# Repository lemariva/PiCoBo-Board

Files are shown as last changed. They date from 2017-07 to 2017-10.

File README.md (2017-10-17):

# PiCoBo-Board 

**PiCoBo** is a multi-target board. I designed it using the **MSP430G2553** (20/28 pin version), which is part of the MSP430 Texas Instruments family of ultra-low-power microcontrollers. 

The board includes also a **CP2102** which can be used for communication over UART. 

The board can be supplied using a C2032 battery, over USB or external DC source up to 10V. It uses a **TPS77301DGK** to regulate the max. voltage of 3.6V needed for the MSP430. 

Up to three **IRLL2705** can be soldered to the board to switch on/off directly (or using PWM) voltages up to 55V and 3.8A. Additionall multiple pinouts are available to connect external sensors (e.g. **DHT11**), servo motors, leds etc. For testing uses it can be programmed using the MSP430G2553 LaunchPad.

Applications
-------------------
* Ultra-low-power sensor: 
	* Temperature
	* Humidity
	* Air quality
	* Light condition
	* Door or window open/close status
	* etc
* Servo controller
* RGB LED controller
* X actuator
* etc

PCB Boards
-----
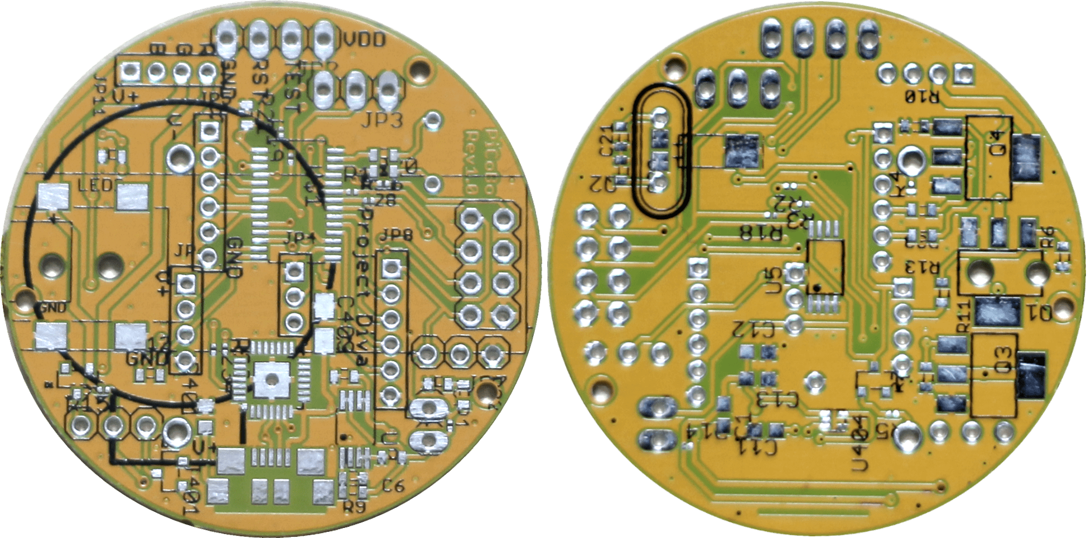
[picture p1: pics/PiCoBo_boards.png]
PCB Boards


More Info: 
-------------------

* Blog article related to this project: https://goo.gl/yuvsjp
* Code example: https://goo.gl/CPGcYK
* Datasheet MSP430G2553: http://www.ti.com/product/MSP430G2553

Changelog
-------------------
* Revision: 1.1v

License
--------------------
Apache 2.0

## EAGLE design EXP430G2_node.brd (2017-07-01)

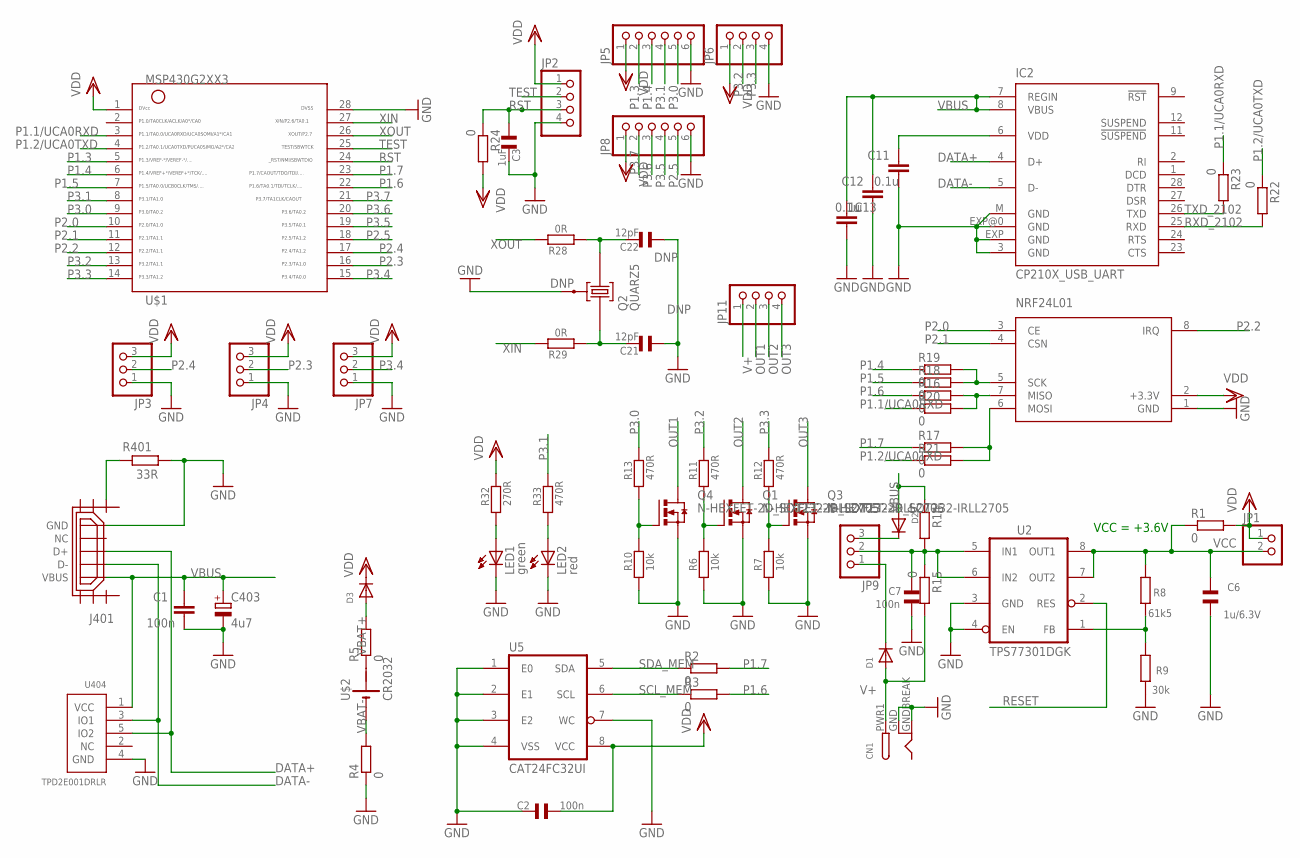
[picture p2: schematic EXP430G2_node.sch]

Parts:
C1: 100n; C0603
C2, C7: 100n; 0603
C3: 1uF; 0603
C6: 1u/6.3V; 0603
C11, C13: 0.1u; C0603
C12: 1u; C0603
C21, C22: 12pF; 0603
C403: 4u7; A/3216-18R
CN1: DCBARRELSMT; DCJACK_2MM_SMT
D1, D2, D3: DIODESOT23_REFLOW; SOT23-R
IC2: CP210X_USB_UART; MLP28
J401: USB_MICRO_FLIPPED; HIROSE-ZX62R-B-5P
JP1: PINHD-1X2; 1X02
JP2: PINHD-1X4; 1X04
JP3, JP7, JP9: PINHD-1X3; 1X03
JP4: PINHD-1X3_2.00; 1X03M
JP5, JP8: PINHD-1X6_2.00; 1X06M
JP6, JP11: PINHD-1X4_2.00; 1X04M
LED1: green; DIODE0603
LED2: red; DIODE0603
NRF24L01: NRF24L01HP; NRF24L01_HP
Q1, Q3, Q4: N-HEXFET-2D_SOT232-IRLL2705; SOT223
Q2: QUARZ5
R1, R2, R3, R4, R5, R14, R15, R16, R17, R18, R19, R20, R21, R22, R23, R24: 0; R0201
R6, R7, R10: 10k; 0603
R8: 61k5; 0603
R9: 30k; 0603
R11, R12, R13, R33: 470R; 0603
R28, R29: 0R; 0603
R32: 270R; 0603
R401: 33R; R0603
U2: TPS77301DGK; MSOP8
U5: CAT24FC32UI; TSSOP8
U404: TPD2E001DRLR; TPD2E001-DRL
U$1: G2XX3---PW28; PW28
U$2: CR2032

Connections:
DATA+: IC2.4 (D+), J401.D+, U404.5 (IO2)
DATA-: IC2.5 (D-), J401.D-, U404.3 (IO1)
GND: C1.2, C2.2, C3.2, C6.2, C7.1, C11.2, C12.2, C13.2, C21.1, C22.1, C403.-, CN1.GND (GNDBREAK), CN1.GNDBREAK (GND), IC2.3 (GND), IC2.EXP (GND), IC2.EXP@0 (GND), IC2.M (GND), J401.GND, JP2.4, JP3.1, JP4.1, JP5.6, JP6.4, JP7.1, JP8.6, LED1.K (C), LED2.K (C), NRF24L01.1 (GND), Q1.3 (S), Q2.GND@0 (0), Q3.3 (S), Q4.3 (S), R4.1, R6.1, R7.1, R9.1, R10.1, R401.2, U2.3 (GND), U2.4 (EN), U5.1 (E0), U5.2 (E1), U5.3 (E2), U5.4 (VSS), U5.7 (WC), U404.4 (GND), U$1.28
unnamed: C7.2, JP9.2, R14.2, R15.1, U2.5 (IN1), U2.6 (IN2)
unnamed: D1.3 (C), JP9.1
unnamed: R8.1, R9.2, U2.1 (FB)
unnamed: D3.1 (A), R5.2
unnamed: Q1.1 (G), R6.2, R11.1
unnamed: NRF24L01.7 (MISO), R16.2, R20.2
unnamed: Q3.1 (G), R7.2, R12.1
unnamed: NRF24L01.6 (MOSI), R17.2, R21.2
unnamed: J401.SHIELD1, R401.1
unnamed: Q4.1 (G), R10.2, R13.1
unnamed: NRF24L01.5 (SCK), R18.2, R19.2
unnamed: LED2.A, R33.1
unnamed: C11.1, IC2.6 (VDD)
unnamed: LED1.A, R32.1
OUT1: JP11.2, Q4.2 (D), Q4.4 (D)
OUT2: JP11.3, Q1.2 (D), Q1.4 (D)
OUT3: JP11.4, Q3.2 (D), Q3.4 (D)
P1.1/UCA0RXD: R20.1, R23.1, U$1.3
P1.2/UCA0TXD: R21.1, R22.1, U$1.4
P1.3: JP5.2, U$1.5
P1.4: JP5.3, R19.1, U$1.6
P1.5: R18.1, U$1.7
P1.6: R3.2, R16.1, U$1.22
P1.7: R2.2, R17.1, U$1.23
P2.0: NRF24L01.3 (CE), U$1.10
P2.1: NRF24L01.4 (CSN), U$1.11
P2.2: NRF24L01.8 (IRQ), U$1.12
P2.3: JP4.2, U$1.16
P2.4: JP3.2, U$1.17
P2.5: JP8.5, U$1.18
P3.0: JP5.5, R13.2, U$1.9
P3.1: JP5.4, R33.2, U$1.8
P3.2: JP6.2, R11.2, U$1.13
P3.3: JP6.3, R12.2, U$1.14
P3.4: JP7.2, U$1.15
P3.5: JP8.4, U$1.19
P3.6: JP8.3, U$1.20
P3.7: JP8.2, U$1.21
RESET: U2.2 (RES)
RST: C3.1, JP2.3, R24.1, U$1.24
RXD_2102: IC2.25 (RXD), R22.2
SCL_MEM: R3.1, U5.6 (SCL)
SDA_MEM: R2.1, U5.5 (SDA)
TEST: JP2.2, U$1.25
TXD_2102: IC2.26 (TXD), R23.2
V+: CN1.PWR1 (PWR), D1.1 (A), JP11.1, R15.2
VBAT+: R5.1, U$2.P$1 (+)
VBAT-: R4.2, U$2.P$2 (-)
VBUS: C1.1, C12.1, C13.1, C403.+, D2.1 (A), IC2.7 (REGIN), IC2.8 (VBUS), J401.VBUS, R14.1, U404.1 (VCC)
VBUS+: D2.3 (C), JP9.3
VCC: C6.1, JP1.2, R1.1, R8.2, U2.7 (OUT2), U2.8 (OUT1)
VDD: C2.1, D3.3 (C), JP1.1, JP2.1, JP3.3, JP4.3, JP5.1, JP6.1, JP7.3, JP8.1, NRF24L01.2 (+3.3V), R1.2, R24.2, R32.2, U5.8 (VCC), U$1.1
XIN: R29.2, U$1.27
XINR: C21.2, Q2.2, R29.1
XOUT: R28.2, U$1.26
XOUTR: C22.2, Q2.1, R28.1

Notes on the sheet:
VCC = +3.6V
DNP

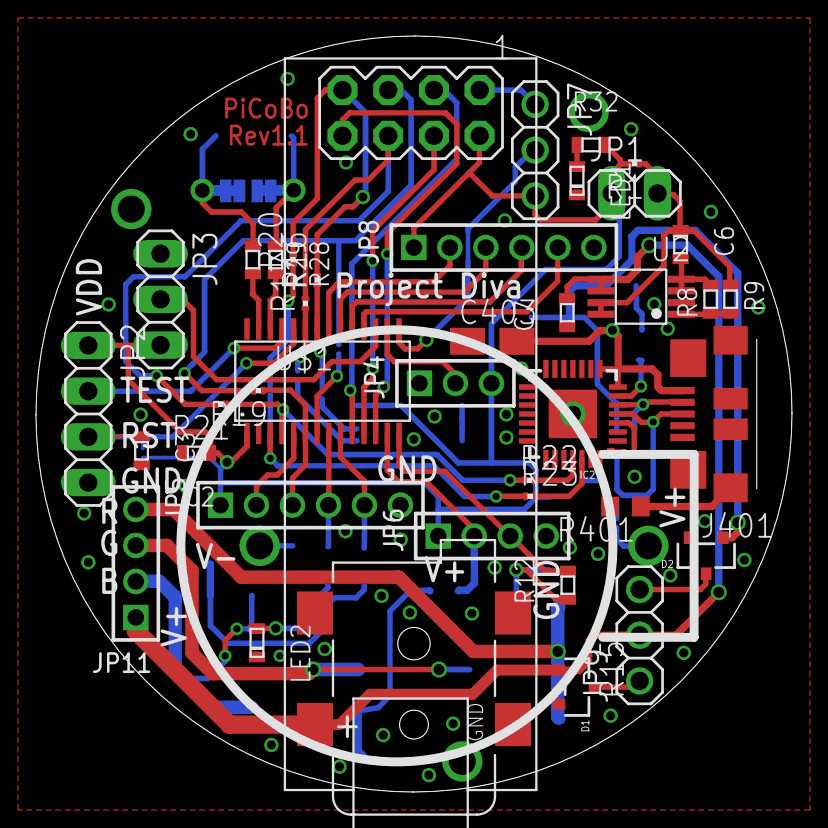
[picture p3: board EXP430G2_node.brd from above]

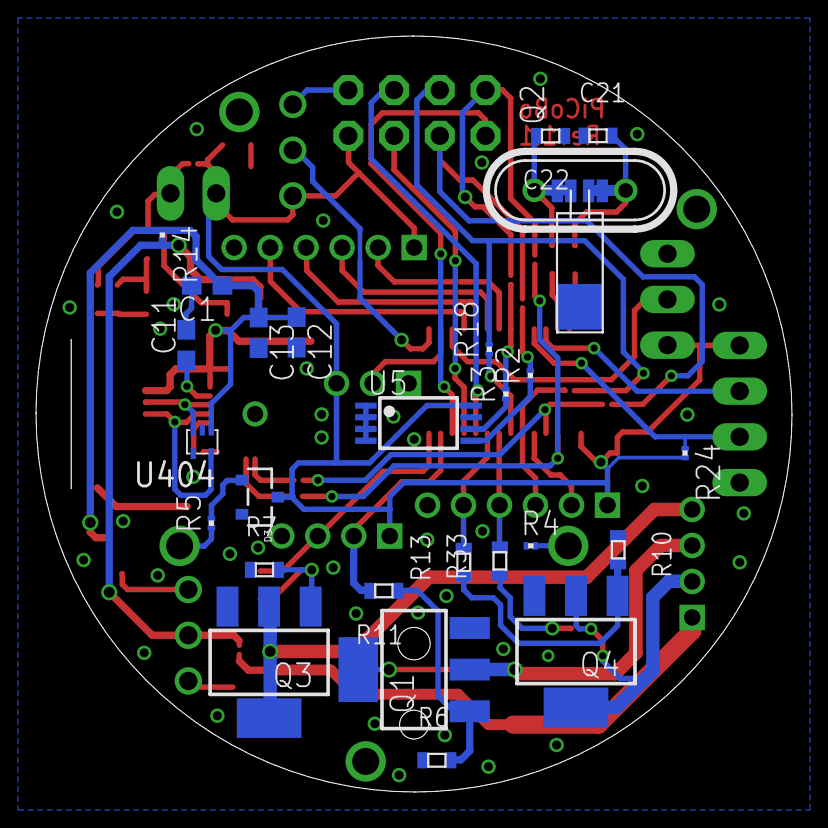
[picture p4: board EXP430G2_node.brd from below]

Board: 2 copper layers, 42.0 x 42.0 mm, 68 parts (26 on the bottom side), 58 nets.
